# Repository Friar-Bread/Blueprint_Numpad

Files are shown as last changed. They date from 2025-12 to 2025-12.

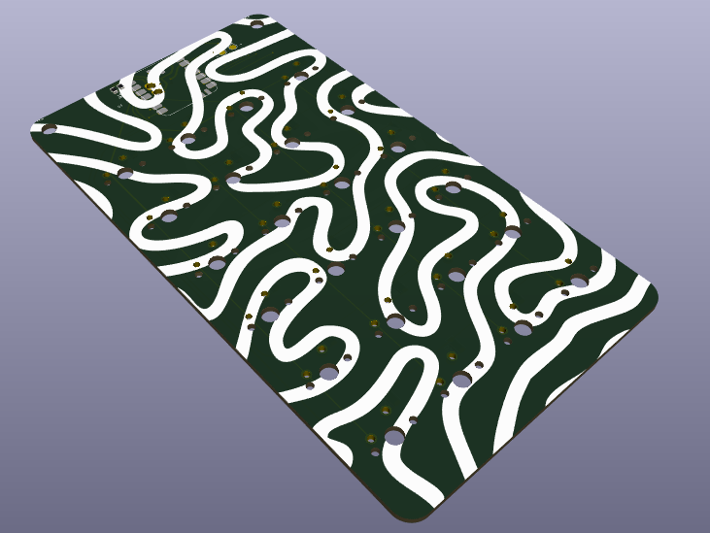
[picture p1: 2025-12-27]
Images/Render_Screenshot_Numpad.png

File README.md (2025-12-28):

# Blueprint_Numpad
Render_Screenshot_Numpad

This numpad is to use for CAD and other programs that use number entry a lot.
I like my smaller keyboard but I often wish I had a numpad which is where this comes in.
I'm using a 4 by 6 layout which is fairly basic but it doesn't have the larger keys that some have.

CAD

[Onshape Link](https://cad.onshape.com/documents/a49eb517829c44ded4fb0486/w/c1ab92566ff330dc74a4adf9/e/f54a2c3f6400f8bab8c2b79a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)

NumpadCAD_Screenshot

Schematic 

Schematic_Screenshot_Numpad

PCB

PCB_Screenshot_Numpad

BOM
| Item | Quant. Needed | Order Quant. | Price  | Link |
| --- | --- | --- | --- | --- |
| PCB | 1 | 5 | $17.43 | JLC PCB
| nRF52840 | 1 | 1 | $9.99  | [link](https://www.seeedstudio.com/Seeed-XIAO-BLE-nRF52840-p-5201.html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) |
|Shipping | | | $6.20
| Keycaps | 24 | 24 | $0.00  | 3D printing |
| Diodes | 24 | 100 | $1.35  | [link](https://www.aliexpress.us/item/3256801808479789.html?) |
| Battery | 1 | 1 | $11.79 | [link](https://www.aliexpress.us/item/3256809787664995.html) |
| Shipping | | | $5.46  | |
| Key Switches | 24 | 40 | $7.08	| [link](https://www.aliexpress.us/item/3256802192387196.html ) |
| 806K Resistor  | 1 | 5 | $0.50  | [link](https://www.digikey.com/en/products/detail/yageo/RC0805FR-07806KL/728163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) |
| 2M Resistor | 1 | 5 | $0.90  | [link](https://www.digikey.com/en/products/detail/te-connectivity-passive-product/CPF0805B2M0E/4966423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) |
| Shipping | | | $4.99  | |
| Total | | | $76.06 | |
| Total with tax | | | $81.38 | |

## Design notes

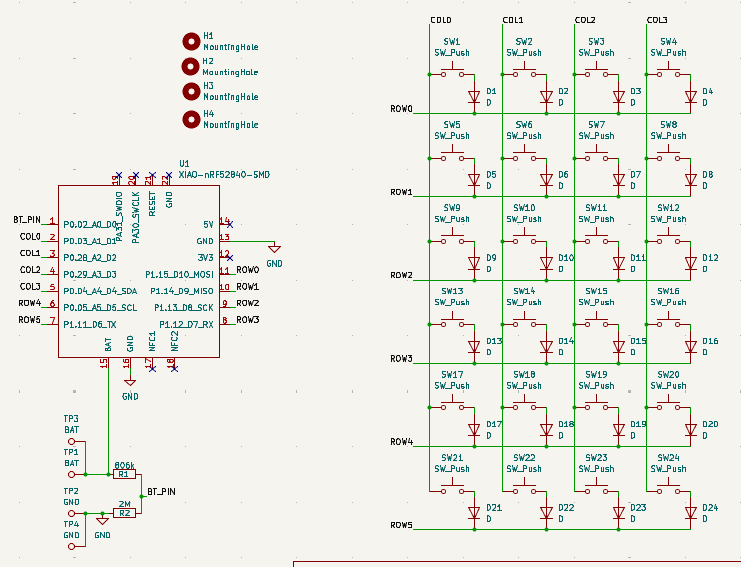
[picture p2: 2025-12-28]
Images/Schematic_Screenshot_Numpad.png

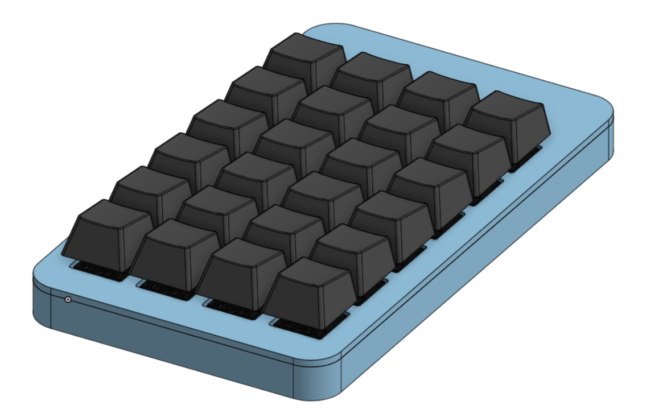
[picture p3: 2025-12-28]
Images/NumpadCAD_Screenshot.png

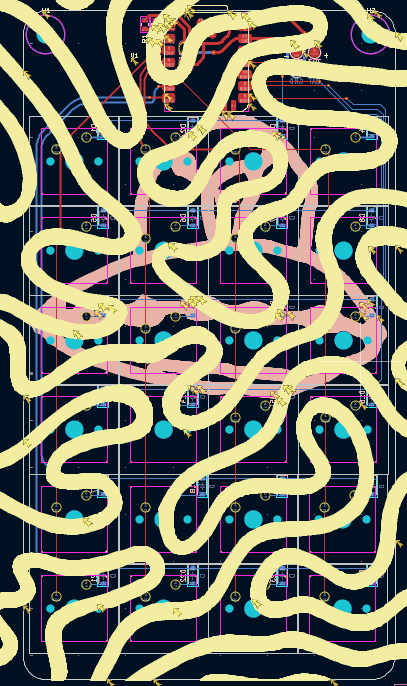
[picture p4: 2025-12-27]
Images/PCB_Screenshot_Numpad.png

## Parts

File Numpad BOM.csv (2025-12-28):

Item | Quant. Needed | Order Quant. | Price | Link
PCB | 1 | 5 | $17.43 | JLC PCB
nRF52840 | 1 | 1 | $9.99 | https://www.seeedstudio.com/Seeed-XIAO-BLE-nRF52840-p-5201.html
Shipping |  |  | $6.20
Keycaps | 24 | 24 | $0.00 | 3D printing
Diodes | 24 | 100 | $1.35 | https://www.aliexpress.us/item/3256801808479789.html?
Battery | 1 | 1 | $11.79 | https://www.aliexpress.us/item/3256809787664995.html
Shipping |  |  | $5.46
Key Switches | 24 | 70 | $7.08 | https://www.aliexpress.us/item/3256802192387196.html
806K Resistor | 1 | 5 | $0.50 | https://www.digikey.com/en/products/detail/yageo/RC0805FR-07806KL/728163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
2M Resistor | 1 | 5 | $0.90 | https://www.digikey.com/en/products/detail/te-connectivity-passive-product/CPF0805B2M0E/4966423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..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
Shipping |  |  | $4.99
Total |  |  | $65.69
Total with tax |  |  | $70.29

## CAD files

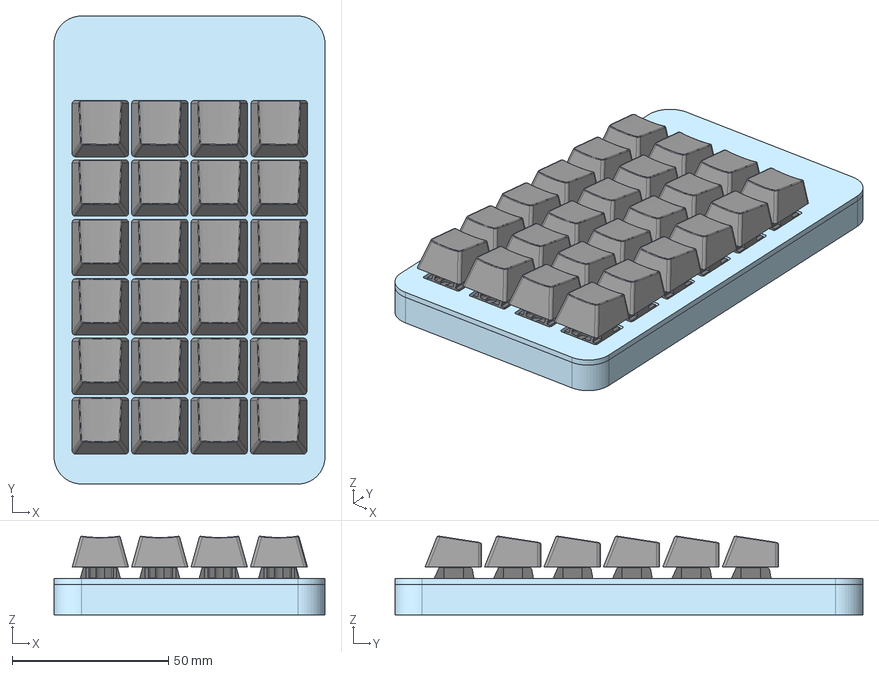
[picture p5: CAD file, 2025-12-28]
CAD/MyNumPad CAD.step
86.6 x 149.6 x 25.1 mm
MyNumPad_PCB
1x1 R1 v23 x 24

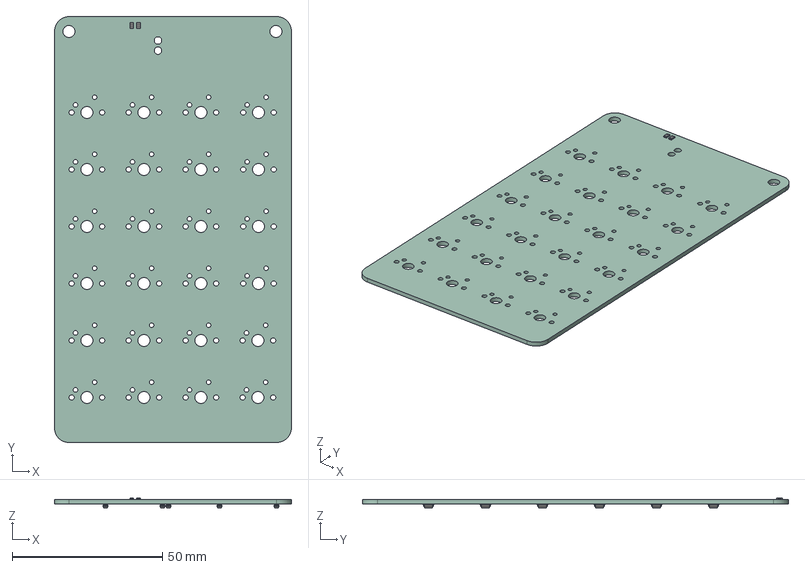
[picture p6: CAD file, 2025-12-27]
PCB/MyNumPad.step
79.0 x 142.0 x 3.39 mm
R_0805_2012Metric x 2
D_SOD-123 x 24
MyNumPad_PCB

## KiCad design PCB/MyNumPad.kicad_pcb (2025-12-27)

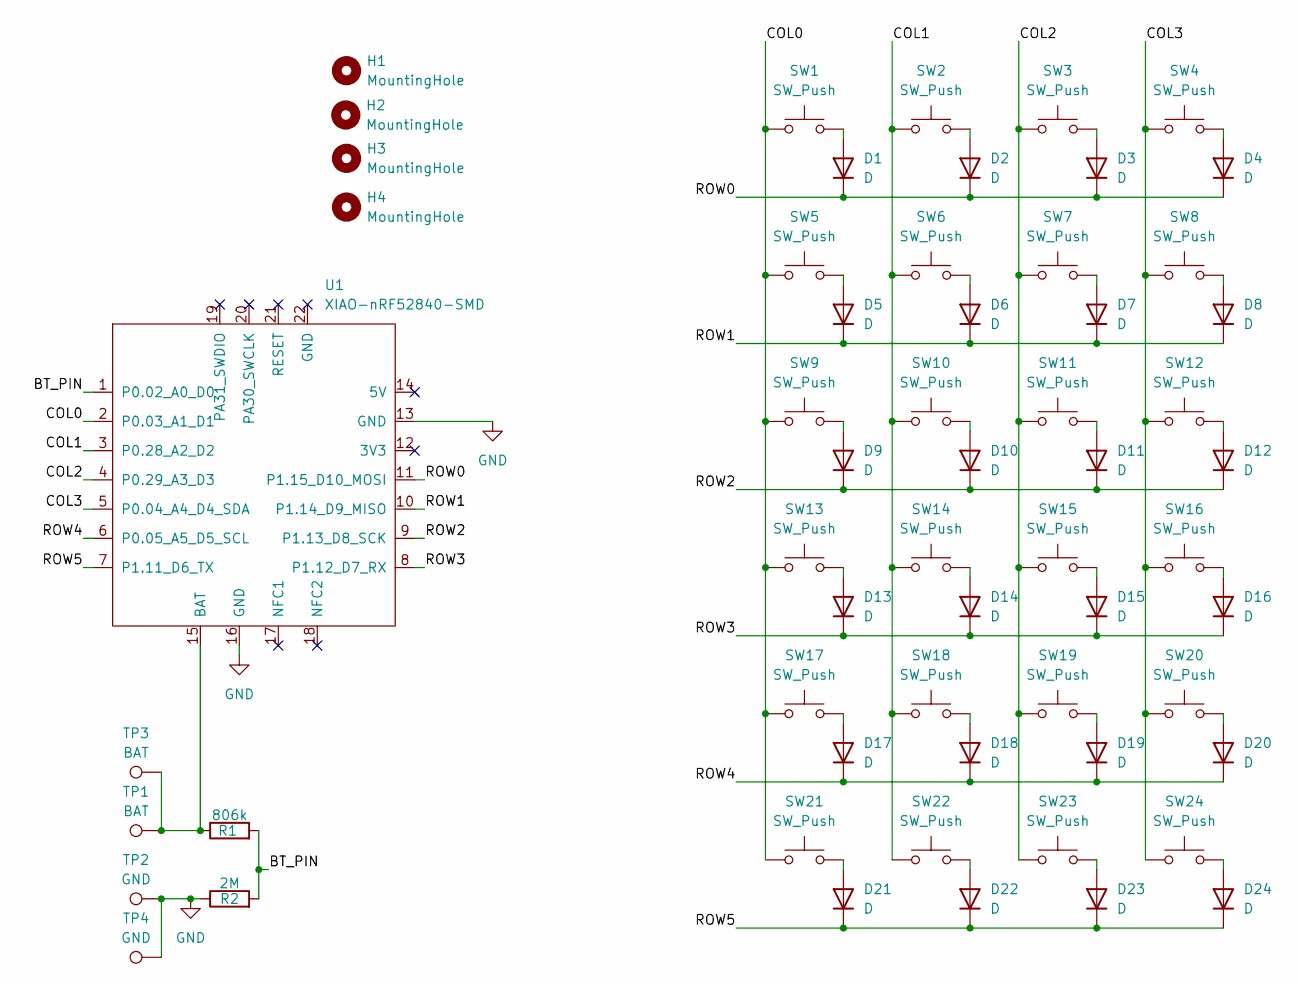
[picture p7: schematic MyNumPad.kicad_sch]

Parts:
D1, D2, D3, D4, D5, D6, D7, D8, D9, D10, D11, D12, D13, D14, D15, D16, D17, D18, D19, D20, D21, D22, D23, D24: D; D_SOD-123
H1, H2, H3, H4: MountingHole; MountingHole_4mm
R1: 806k; R_0805_2012Metric
R2: 2M; R_0805_2012Metric
SW1, SW2, SW3, SW4, SW5, SW6, SW7, SW8, SW9, SW10, SW11, SW12, SW13, SW14, SW15, SW16, SW17, SW18, SW19, SW20, SW21, SW22, SW23, SW24: SW_Push; SW_MX_1u
TP1, TP3: BAT; TestPoint_Pad_D2.0mm
TP2, TP4: GND; TestPoint_Pad_D2.0mm
U1: XIAO-nRF52840-SMD; modified-XIAO-nRF52840-SMD

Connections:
/BT_PIN: R1.2, R2.2, U1.1 (P0.02_A0_D0)
/COL0: SW1.1, SW5.1, SW9.1, SW13.1, SW17.1, SW21.1, U1.2 (P0.03_A1_D1)
/COL1: SW2.1, SW6.1, SW10.1, SW14.1, SW18.1, SW22.1, U1.3 (P0.28_A2_D2)
/COL2: SW3.1, SW7.1, SW11.1, SW15.1, SW19.1, SW23.1, U1.4 (P0.29_A3_D3)
/COL3: SW4.1, SW8.1, SW12.1, SW16.1, SW20.1, SW24.1, U1.5 (P0.04_A4_D4_SDA)
/ROW0: D1.1 (K), D2.1 (K), D3.1 (K), D4.1 (K), U1.11 (P1.15_D10_MOSI)
/ROW1: D5.1 (K), D6.1 (K), D7.1 (K), D8.1 (K), U1.10 (P1.14_D9_MISO)
/ROW2: D9.1 (K), D10.1 (K), D11.1 (K), D12.1 (K), U1.9 (P1.13_D8_SCK)
/ROW3: D13.1 (K), D14.1 (K), D15.1 (K), D16.1 (K), U1.8 (P1.12_D7_RX)
/ROW4: D17.1 (K), D18.1 (K), D19.1 (K), D20.1 (K), U1.6 (P0.05_A5_D5_SCL)
/ROW5: D21.1 (K), D22.1 (K), D23.1 (K), D24.1 (K), U1.7 (P1.11_D6_TX)
GND: R2.1, TP2.1, TP4.1, U1.13 (GND), U1.16 (GND)
unnamed: D1.2 (A), SW1.2
unnamed: D2.2 (A), SW2.2
unnamed: D3.2 (A), SW3.2
unnamed: D4.2 (A), SW4.2
unnamed: D5.2 (A), SW5.2
unnamed: D6.2 (A), SW6.2
unnamed: D7.2 (A), SW7.2
unnamed: D8.2 (A), SW8.2
unnamed: D9.2 (A), SW9.2
unnamed: D10.2 (A), SW10.2
unnamed: D11.2 (A), SW11.2
unnamed: D12.2 (A), SW12.2
unnamed: D13.2 (A), SW13.2
unnamed: D14.2 (A), SW14.2
unnamed: D15.2 (A), SW15.2
unnamed: D16.2 (A), SW16.2
unnamed: D17.2 (A), SW17.2
unnamed: D18.2 (A), SW18.2
unnamed: D19.2 (A), SW19.2
unnamed: D20.2 (A), SW20.2
unnamed: D21.2 (A), SW21.2
unnamed: D22.2 (A), SW22.2
unnamed: D23.2 (A), SW23.2
unnamed: D24.2 (A), SW24.2
unnamed: R1.1, TP1.1, TP3.1, U1.15 (BAT)

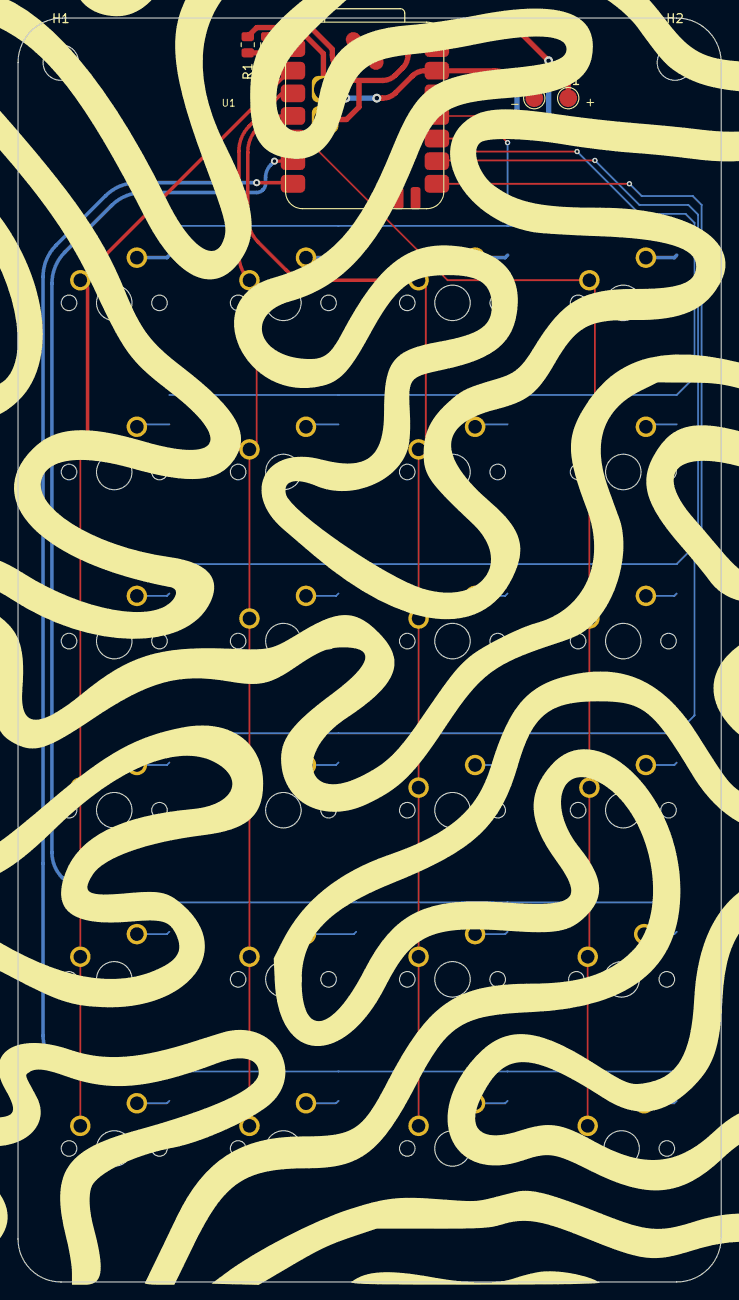
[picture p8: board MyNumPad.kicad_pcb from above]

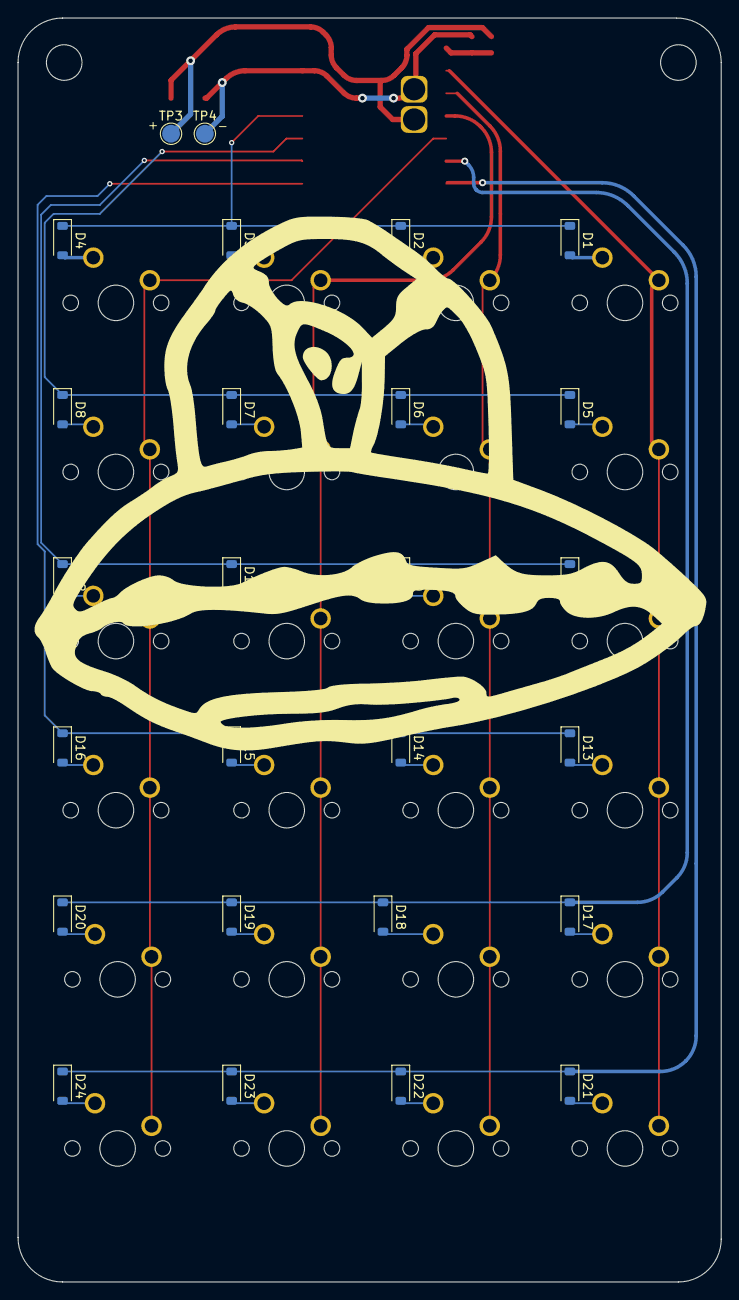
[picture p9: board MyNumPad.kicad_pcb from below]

Board: 2 copper layers, 79.0 x 142.0 mm, 57 parts (26 on the bottom side), 37 nets.

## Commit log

2025-12-27 BOM and folders
    [Numpad BOM.csv]
2025-12-27 added CAD
    [Feet CAD.step]
2025-12-27 PCB stuff
    [MyNumPad.kicad_pcb, MyNumPad.kicad_sch, MyNumPad.step]
2025-12-28 Update Numpad BOM.csv
    [Numpad BOM.csv]
2025-12-28 Update README bom.md
2025-12-28 updated CAD
    [Feet CAD.step, MyNumPad CAD.step]
2025-12-28 changed schematic image
2025-12-28 update BOM
    [Numpad BOM.csv]
